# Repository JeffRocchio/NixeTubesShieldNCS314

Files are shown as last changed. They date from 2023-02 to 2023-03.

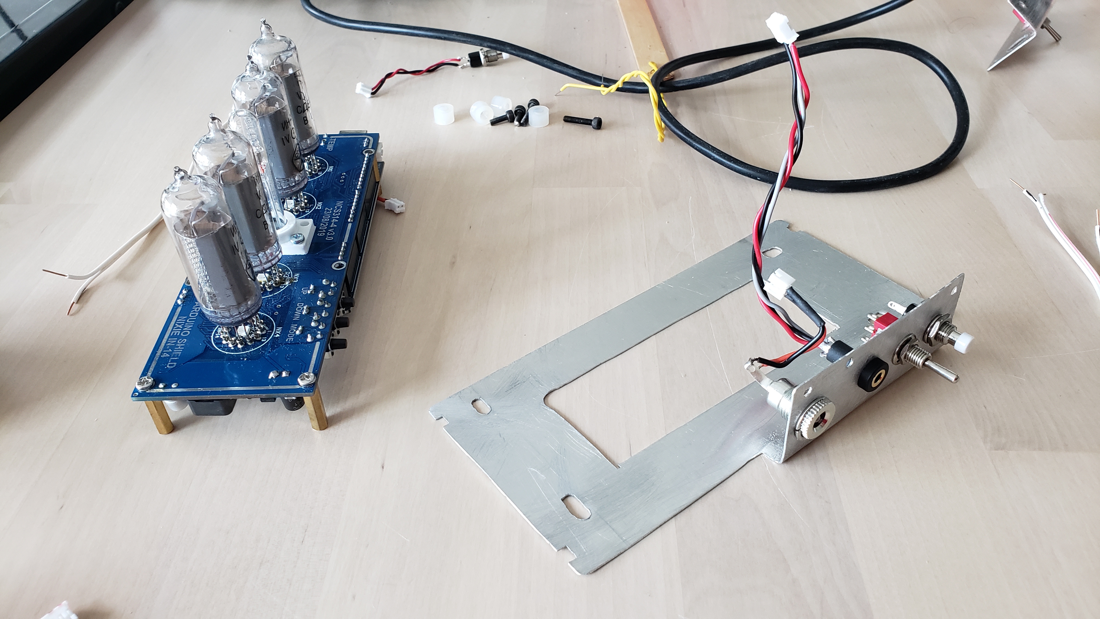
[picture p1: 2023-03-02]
Case/Fabrication_Bottom-Plate_02.jpg

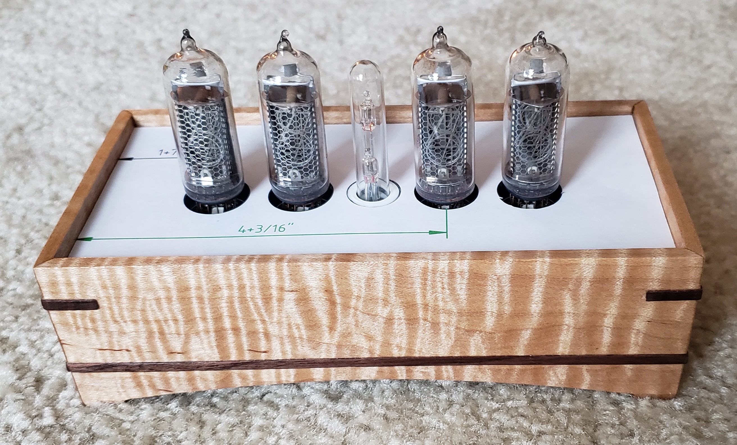
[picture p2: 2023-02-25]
Case/Fabrication_Ready4TopPlate.jpg

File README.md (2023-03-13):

This repo contains my personal customizations for the Nixi-Tube clock I purchased, and assembled, from GRA & AFCH in early 2023.

The clock is their Arduino Shield Nixie IN-14 model. I purchased the kit and assembled it; and with the help of a woodworking friend made a case for it.

<b>NOTE</b>: As of 3/13/2023 this clock does not support automatic Daylight Savings / Standard Time sensing and adjustment. To adjust for daylight savings if using the GPS receiver to sync time, you need to set the "timezone" ahead by one hour. levinedl's github has code for auto daylight savings adjustment, which was submitted as a pull request to gra-afch, tho they have ignored it. Sometime prior to the next shift back to Standard Time in the US I plan to review and incorporate levinedl's DST branch into my own code. See @ https://github.com/levinedl/NixeTubesShieldNCS314/tree/dst/Firmware/Source%20code/Hardware%20Version%203.x%20(HW3.2)/NixieClockShield_NCS314.

Per original GRA & AFCH Readme:

Sketch for Arduino UNO and Nixie Tubes Shield NCS314 and NCS312 by GRA &amp; AFCH

1. This repository content sources of project for Nixie Clock developed by GRA & AFCH.

	Folders description:
  
	FIRMWARES - source code that must be complied in Arduino IDE, and allready compiled Binary files in *.hex format ready to be uploaded on to property board by flasher.
  
	GRA & AFCH Compiled Firmware Flasher - flasher (uploader) that must be used in prevois step.
  
	LIBRARIES - Arduino libraries without which compiling will be failed. That folders must be copied to Arduino LIBRARIES folder, (default path: C:\Users\USER_NAME\Documents\Arduino\libraries)
  
	SCHEMES - electrical shemes for boards: for Nixie Clock Main Units - MCU, and for Nixie Tubes Boards
  
	USB DRIVERS - drivers for USB-to-SERIAL(UART) converters
  
	USER MANUAL - end user's manuals.

2. Link to YouTube video with preparing, compiling and uploading firmware to clock:
https://youtu.be/DQZWPn0iAHw

3. Compatibility:

	Nixie Clock Shield for Arduino - <b>NCS314</b> (Hardware Versions: HW1.0, HW1.1, HW1.2, HW2.0, HW2.2) <br>
	Nixie Clock Shield for Arduino - <b>NCS312</b> (Hardware Versions: HW1.0 - HW1.3) - use the firmware for NCS314 version 2.0
	
The GRA & AFCH on-line presence is at: http://gra-afch.com

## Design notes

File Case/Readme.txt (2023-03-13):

Custom Wooden Case for Nixi Clock

With the help of a woodworking friend I make my own case for the clock. This folder contains some photos and FreeCAD files I used to help with the design and fabrication.

NOTE: File: Nixie_Clock_SHIELD_NCS314_v3.4-4Tubes.rar is a compressed, archive, file that contains a CAD 'step' file from the GRA & AFCH web site which contains a 3D rendering of the completed circut board (but without the Arduino). I didn't discover this existed until after I had made my case. Assuming this CAD file is accurate it could be a big help in using a CAD tool, such as FreeCAD, to design, dimension, and fabricate a case.

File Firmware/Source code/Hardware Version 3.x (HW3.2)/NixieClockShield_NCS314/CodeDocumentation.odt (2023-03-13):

Nixi Tube Clock

# Arduino Code Documentation

Release tbd

This document contains detailed Arduino code documentation for the GRA & AFCH Nixi Tube clock, model Arduino Shield Nixie IN-14 Musescore plugin. Within the code are reference numbers in the form of CD-##. Those are pointers to the matching reference ID number within this document.

## Outstanding TO-DOs

Ref# | TO-DO Description
| EU/US Date Flip. The thing where the euro date format shows first for a flash, then it flips to the US date format.
| Create Night Sleep Timer: Create code to put the display tubes to sleep at night, and auto-wake up in the morning.

Add Support for Daylight Savings Time: On March 12, 2023 I noted that the clock does not automatically recognize DST. When I set the time ahead 1-hour manually (using the buttons on the back of the clock) it kept reverting back to Standard Time. After looking at the code I realized that it was doing this because when it updated the time from the GPS satellites it was simply using the hoursOffset variable to set the local time. And of course the GPS system is giving the clock UTC, with no time zone or daylight savings info. So the work-around is to set the “timezone” ahead by one hour. (And really “timezone” isn’t really a timezone, it is simply the number of hours to add/subtract from UTC in order to get the local time.) So I’d like to add support for automatic daylight savings / standard time adjustment to the software.

2023-03-13: In poking around the GRA github site I saw an ignored pull request where a Mr. Levine had created the code for this already. So this is where I should start. That is, study his code and adopt as-is or modify for my own use as appropriate. See @ https://github.com/levinedl/NixeTubesShieldNCS314/blob/dst/Firmware/Source%20code/Hardware%20Version%203.x%20(HW3.2)/NixieClockShield_NCS314/dst.ino

## Code Documentation

Ref# | Documentation

CD-01

Turn Off Arduino Internal Green LED & Remove IR Remote Feature. This is harder than it looks. Turns out that the Arduino SPI SCK and MOSI signals at pins D51 & D52 have been tied to pins D11 and D13. You can see this is the schmatic. So if you mess with pin-13, which is the hard-coded pin that the Arduino internal LED is connected to, you interfere with the clock signal for the IC which drives the nixi tube display segments (the HV57708 chip). I asked GRA/AFCH about this:

“We do not use pin 13 in our Clocks in our current configuration. And the connection is made for compatibility reasons between the UNO and MEGA, including the older versions.”

So based on this I bent over the header pin that connects into the Arduio at pin-13, such that it no longer connects into the Arduino, so that I could control PIN-13 from the Arduino code and turn that LED off in the setup code.

BUT – it also turns out that deep in the code for the infrared remote control feature is a function that blinks the internal LED on pin-13. This is inside Irremote.h. Line 81 is: # define BLINKLED 13.

Since I will never use an IR remote with this clock I have removed all the code associated with the IR remote control.

Last Update: 2023-02-12
CD-02 | RGB LEDs on One Fixed Color. This is a user-configurable feature through the mode setting functions. In the code the variable “LEDsLock” holds this setting. If LEDsLock is TRUE then the backlight LEDs are fixed on one color. The setting of LEDsLock is persistently stored in the EEPROM. If LEDsLock is TRUE, then the RDG LED colors are set from the R, G, B values that are stored in EEPROM. So you’ll see, for example: if (LEDsLock == 1) setLEDsFromEEPROM(); And void setLEDsFromEEPROM() is defined in the module rotateFireWorks_SK.ino.

CD-03

Intensity of RGB LED Under the Blinking Dots Column. Because, for me, the LED that is under the blinking dots column shines too bright, and interferes with the appearence of the blinking dots I created ability to lower the intensity of the RGB-LED under the dots column.

NOTE-1: Since I have the 4-digit clock (HH:MM) I did not attempt to make the code work for clocks with two dot columns.

NOTE-2: I hard-coded an intensity adjustment into my patch. There is no provision for a user-configurable setting via the back panel controls. To adjust the intensity you have to change the code in the the rotateFireWorks_SK.ino module.

Note-3: As I find the rotating color changes of the LEDs default behavior to be too distracting, I have set my clock to display only a single LED backlight color. Thus I have attempted to add this change to the color rotation code. However, doing so is probably just a matter of copying the code change I made in setLEDsFromEEPROM() over to the rotateFireWorks() function.

Taking note of CD-02 above, this change is implemented via updates to code that is in the rotateFireWorks_SK.ino file.

Approach: In the loop where the LED colors are set and displayed, inside of setLEDsFromEEPROM(), I reduce each R,G,B color value for the column’s pixel by the #define COLdim statement at the top of the rotateFireWorks_SK.ino file. Reducing the value of each color has the effect of retaining the set color, but dimming the brightness.

Last Update: 2023-03-02
CD-04
CD-05
CD-06

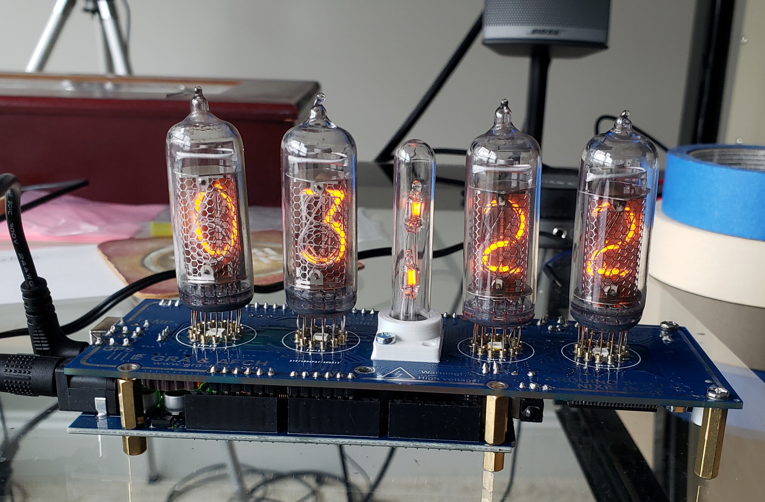
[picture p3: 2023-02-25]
Case/20230116_Bare-Chassis.jpg

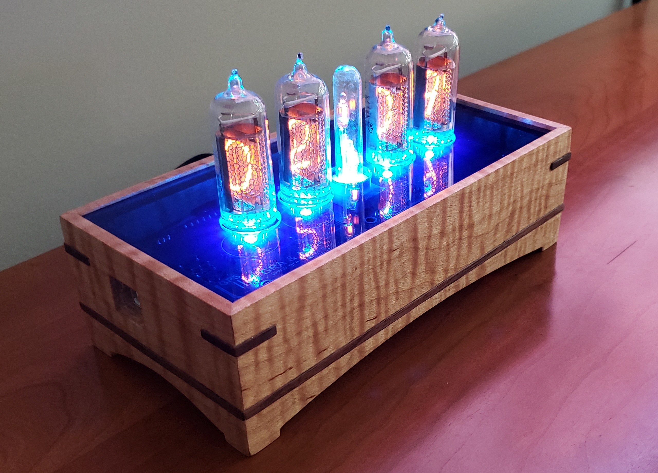
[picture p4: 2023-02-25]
Case/Finished-Case-in-Use_03.jpg

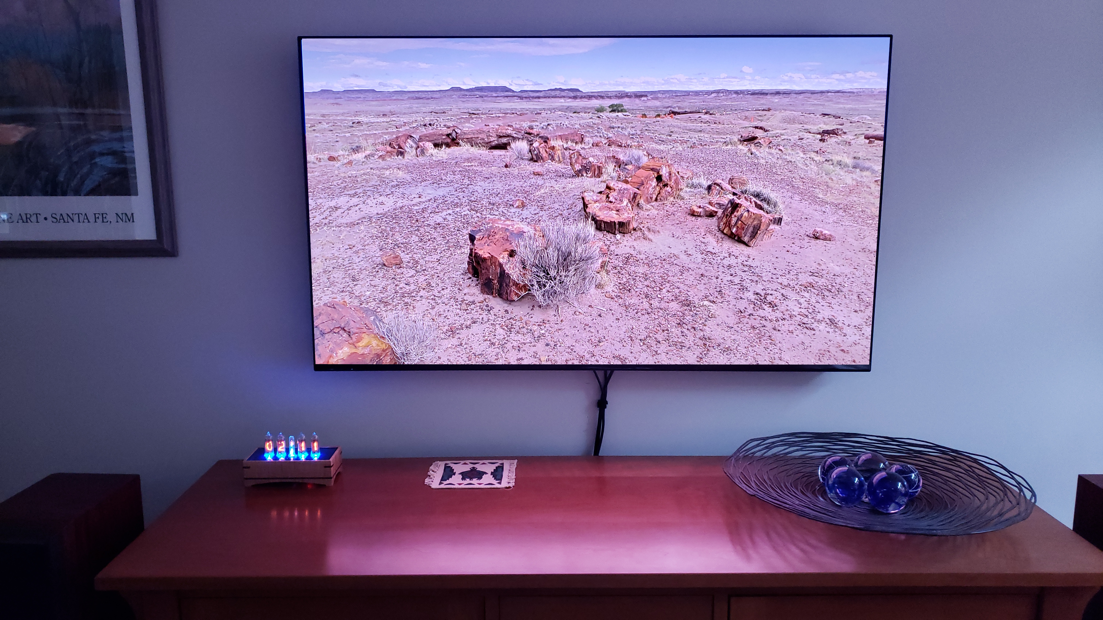
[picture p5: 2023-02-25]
Case/Finished-Case-in-Use_09.jpg

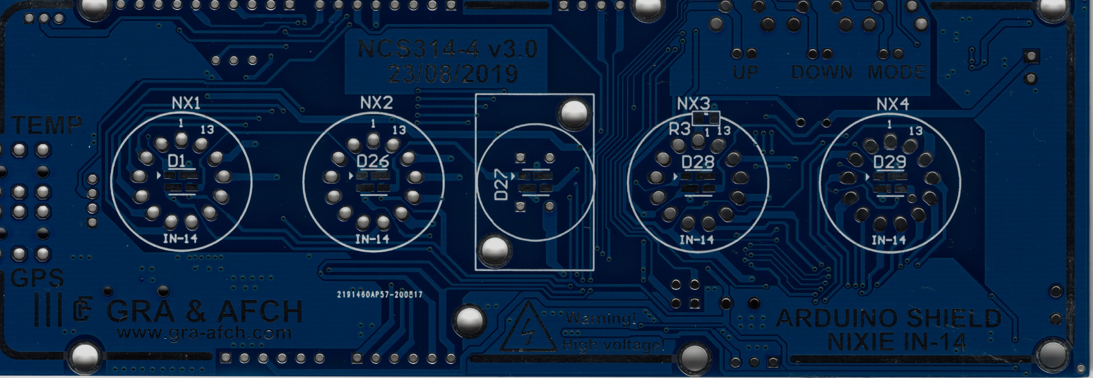
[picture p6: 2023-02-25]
Case/NixiTubeClock_CircutBoard_Scan.jpg

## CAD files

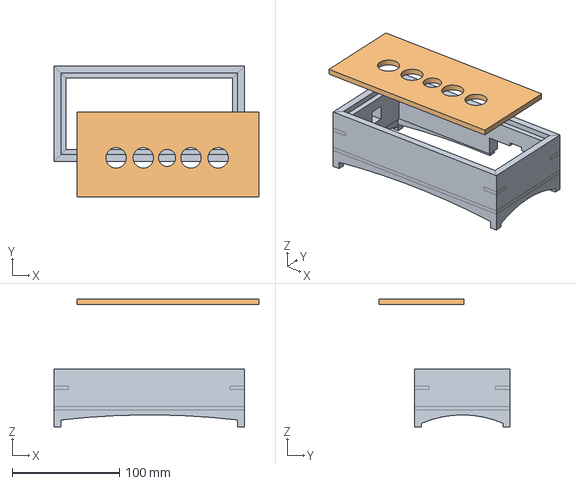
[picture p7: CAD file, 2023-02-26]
Case/FreeCAD_JeffsCase.FCStd
191.3 x 122.2 x 119.1 mm
Top Plate

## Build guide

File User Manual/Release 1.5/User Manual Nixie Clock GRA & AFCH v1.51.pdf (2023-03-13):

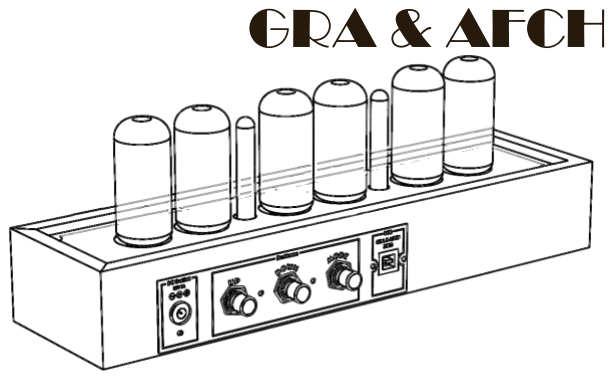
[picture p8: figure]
GRA & AFCH

# Divergence Meter

# NIXIE CLOCK

# OPERATING INSTRUCTION

2036
Release 1.51

GENERAL GUIDE

1. Press “Mode” to change fro m mo de to mode. Each mo de is ex plained in det ail o n t he fo llo wing pages.

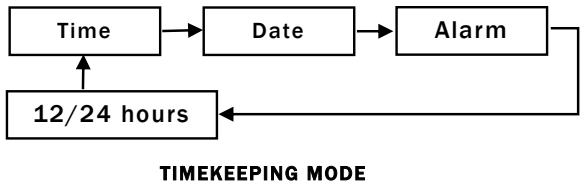
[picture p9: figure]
TIMEKEEPING MODE; Time; Date; Alarm; 12/24 hours

To set t he digit al time

1. Hold do wn “Mo de” while in t he Timekeeping Mo de unt il t he ho urs digit s start to flash. The hours flash because t hey are s elect ed.
2. Press “Mo de” to change t he selectio n in t he fo llo wing sequence:
- Once yo u reach t he Timekeeping display, yo u have to ho ld do wn “Mo de” again to display flashing ho urs.
- While the digits are select ed (flashing), hold do wn “Mode” to ret urn in Timekeeping Mo de wit hout saving.
3. While any digit s are selected, press “U p” to increase t he number, or “Do wn” to decrease t he number. Ho lding do wn “U p” or “Do wn” changes t he current selectio n at high speed.
4. Aft er you set the time, press “Mode” to select t he Timekeeping Mo de.
- If yo u do not operat e any butt on for a few minut es while select io n is flashing, the flashing sto ps and t he clo ck go es back to the Timekeeping Mo de auto mat ically .

DATE MODE

To set t he dat e

1. Hold do wn “Mo de” while in t he Dat e Mo de until the days digit s st art to flash. The day s digit s flash because t hey are selected.
Hours | Minutes | Seconds

## Timekeeping

2. Press “Mo de” to change select io n in follo wing sequence:
- Once yo u reach t he Dat e Mode , you have t o hold do wn “Mo de” again to display t he flashing day s.
- While the digits are select ed (flashing), hold do wn “Mode” to ret urn in Timekeeping Mo de wit hout saving.
3. While any digit s are selected, press “U p” to increase t he number, or “Do wn” to decrease t he number. Ho lding do wn “U p” or “Do wn” changes t he current selectio n at high speed.
4. Aft er you set t he dat e, press “Mo de” to select t he Date Mo de.
- If yo u do not operat e ant butt on fo r a few minut es while a select io n is flashing, the flashing sto ps and clock goes back to the Dat e Mode auto mat ically .
- The clo ck do es make validat io n for co rrect dat e. So clo ck not t o ret urn to Dat e Mo de if dat e is incorrect.

ALARM MODE

When the Daily Alarm Functio n is swit ched on, t he alarm sounds at t he preset t ime each day. Press any butto n to st op t he alarm after it st art s to so und.

To set t he alarm time

1. Hold do wn “Mo de” while in Alarm Mo de until t he ho ur digits st art to flash. The hour digit s flash because they are s elect ed.
2. Press “Mo de” to change select io n in t he fo llo wing s equ ence.
- Press “U p” o r “Do wn” butto ns t o increase o r decrease select ed digit s. Holding down butto ns changes the select io ns at high speed.
Days | Months | Years

## Date Mode

# web-site: www.gra-afch.com

- Daily alarm o n/o ff mo de is represent ing by upper separat e dot s, press “Up” o r “Do wn” to enable o r disable daily alarm.
- Ent ering in Alarm Mo de alway s swit ch daily alarm on.
- If y ou do not o perat e any butto ns a few minut es while a selectio n is flashing, t he flashing sto ps and t he clock go es to t he Timekeeping Mo de.

12/24 Hours Mode
To change 12/24 mo de
1. Ent er in 12/24 mode sett ings, by ho lding do wn “Mode” butt o n while in 12/24 mode until 12 o r 24 digit s st art to flash.
2. Press “U p” or “Do wn” butto ns to swit ch bet ween 12 and 24 mo des.
3. Aft er yo u set t ime format press “Mode” butto n to return i n Timekeeping mo de.
- If y ou do not o perat e any butto ns a few minut es while a selectio n is flashing, t he flashing sto ps and t he clock go es to t he Timekeeping Mo de
LED Backlight
To disable LED backlight
1. Hold down “Do wn” unt il t he LED backlight turns o ff.

To enable LED backlight
1. Hold down “U p” until the LED backlight t urns o n.

To fix co lo r of LEDs
1. Press “Do wn” butto n.

To resume auto mat ic LEDs co lo r changing
1. Pres “U p” butt on.

POWER ON SELF TEST
Immediat ely aft er a clo ck is po wered o n Self- Test is st arting in the follo wing sequence:
1. Red LEDs o n.
2. Green LEDs o n.
3. Blue LEDs on.
4. Tubes test which display all digit s fro m 0 to 9 on all t ubes simultaneo usly.
5. Input vo lt age t est.
6. Firmware versio n.
7. Sound t est .

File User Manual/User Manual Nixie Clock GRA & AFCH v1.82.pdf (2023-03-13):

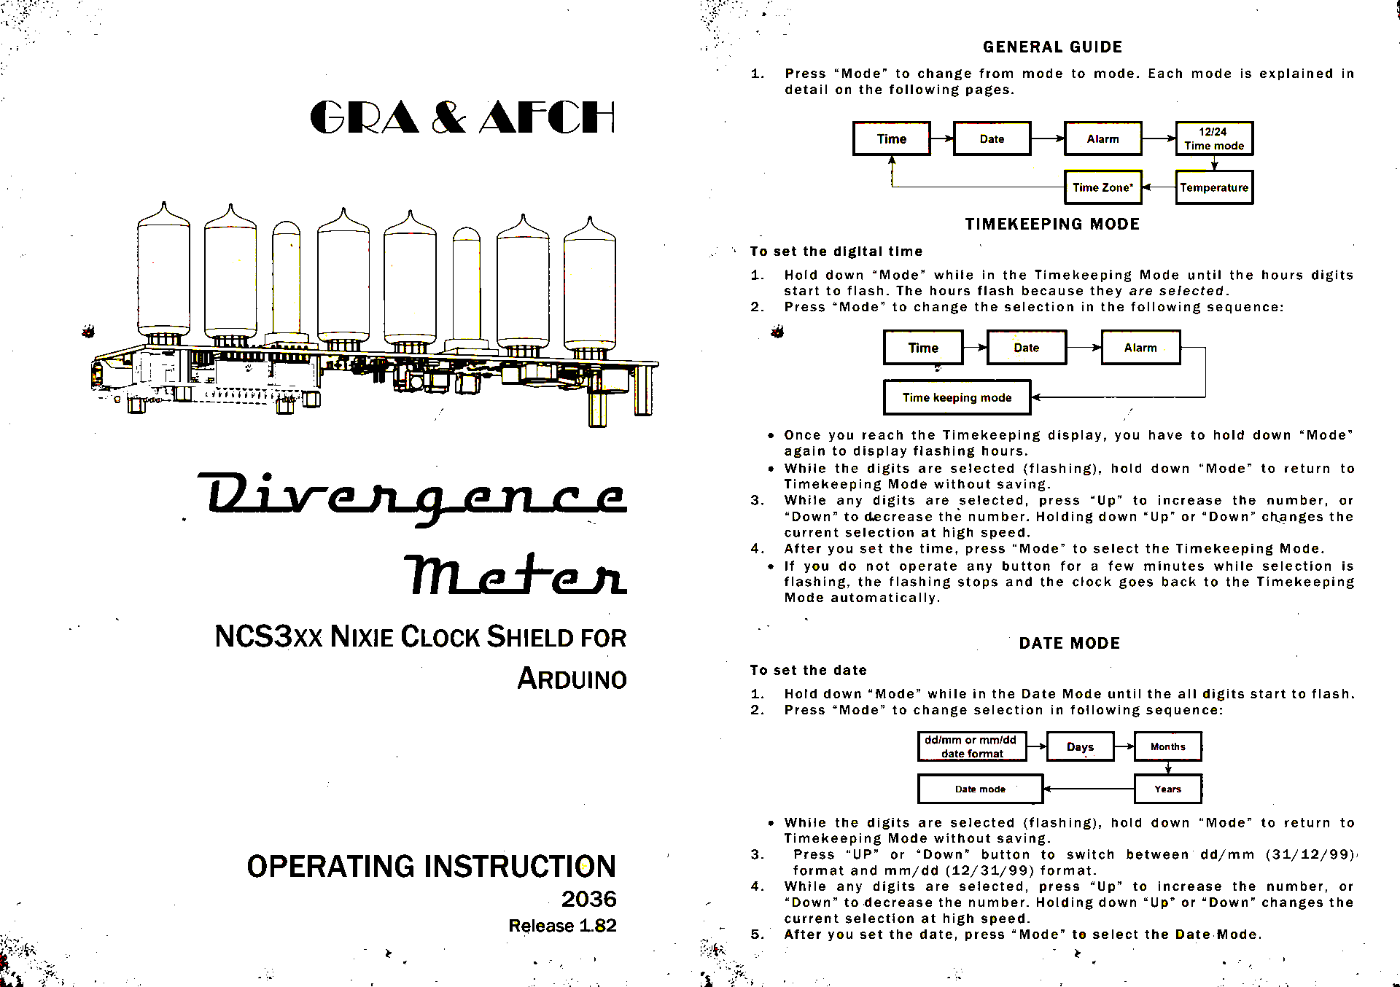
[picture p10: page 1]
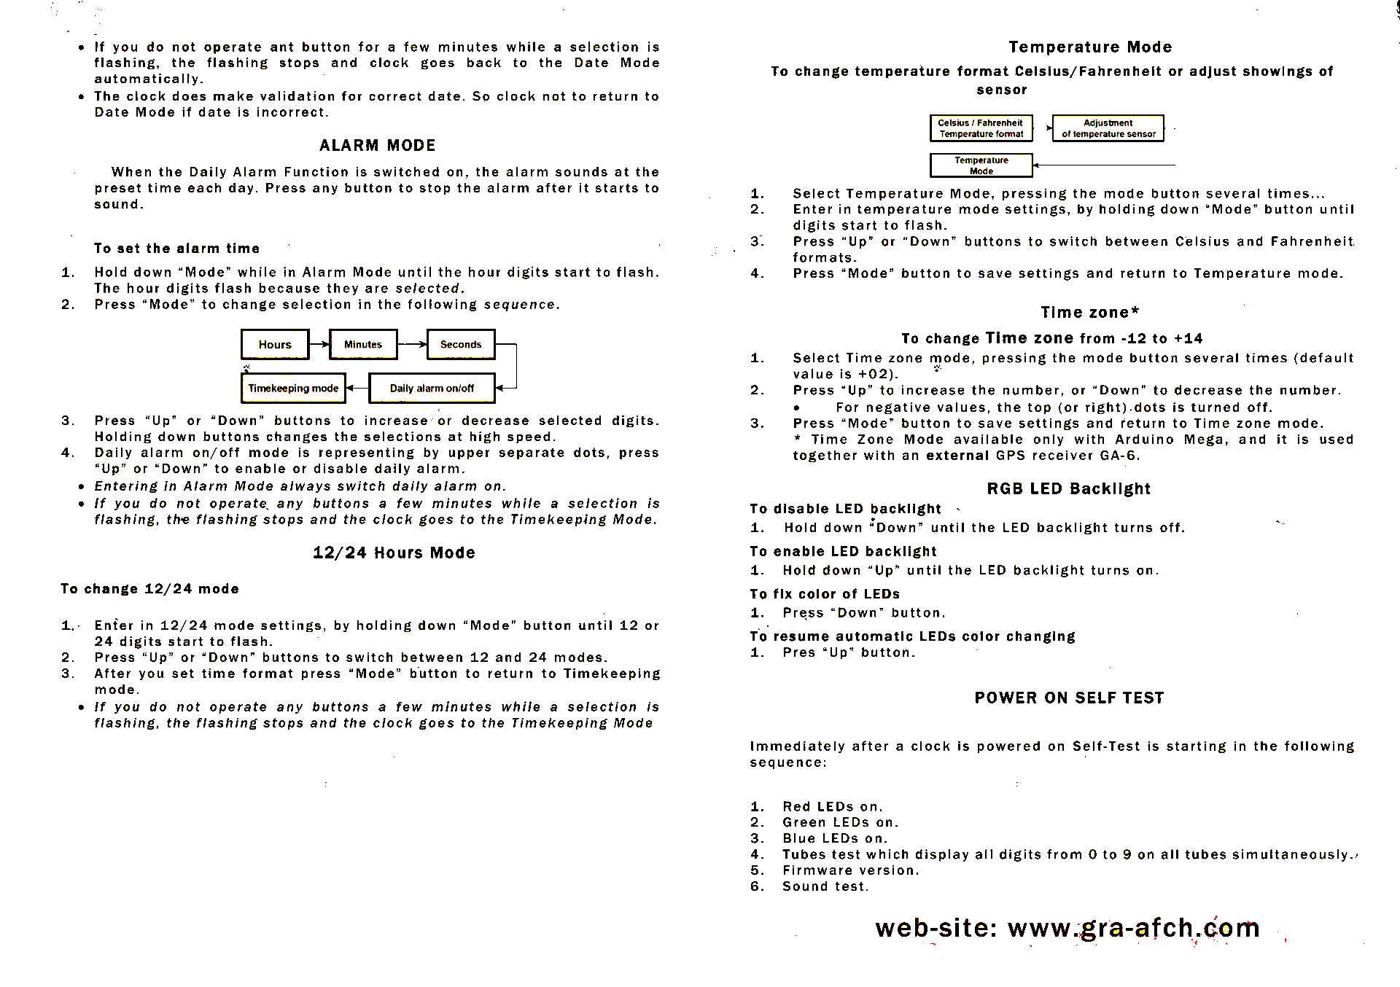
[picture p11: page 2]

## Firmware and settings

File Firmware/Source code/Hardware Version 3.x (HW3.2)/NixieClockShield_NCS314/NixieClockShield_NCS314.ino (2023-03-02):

/******************************************************************************/
//  Jeff Rocchio's Customizations.

/*  2023-03-02_a
        - Created ability for intensity of the RGB-LED under the dots column
      to be less than the intensity of the LEDs under the tubes.
      Did this because for me that LED shines too bright and interferes with
      the appearence of the blinking dots.
      NOTE-1: Since I have the 4-digit clock (HH:MM) I did not attempt to make
      the code work for clocks with two dot columns.
      NOTE-2: I hard-coded an intensity adjustment into my patch. There is
      no provision for a user-configurable setting via the back panel
      controls. To adjust the intensity you have to change the code
      in the the rotateFireWorks_SK.ino module. See the statement: #define COLdim
      See documentation note CD-03 in CodeDocumentation.odt. */

/*  2023-02-12_a
        - Removed all code associated with the IR remote control. Not only
      because I will never use this, but also because it makes use of the
      Arduino's internal LED, which prevents me from turning it off.
      See documentation note CD-01 in CodeDocumentation.odt. */

/*  2023-02-12_b
        - Turn Arduino internal LED off (as it is so bright it shines up through
      the board). NOTE: to make this work I had to bend the header pin that
      connects to Arduino pin 13 over so that the clock signal connected to
      that header pin doesn't come into the Arduino. See Documentation
      note CD-01 in CodeDocumentation.odt. */



// TO-DOs: --------------------------------------------------------------------

/* GPS Validation always 'failing
    In GPS_Parse_DateTime() it keeps falling
    into the 'Validation failed' serial.print. Yet the prior prints do show
    it is getting the time value from the GPS. So what's that about? */

/* Date:
    The thing where the euro date format shows first for a flash, then
    it flips to the US date format. */

/* Create Night Sleep Timer:
    Create code to put the display tubes to sleep at night, and auto-wake up
    in the morning. */

/*******************************************************************************/



const String FirmwareVersion = "020100"; // jrr 2023-02-12: Changing ver# for my updates. For now, Month & sequence #.
//const String FirmwareVersion = "019500";
//#define HardwareVersion "NCS314 for HW 3.x" 
const char HardwareVersion[] PROGMEM = {"NCS314 for HW 3.x"};
//Format                _X.XXX_
//NIXIE CLOCK SHIELD NCS314 v 3.x by GRA & AFCH (fominalec@gmail.com)
//1.95 14.01.2021
//GPS ANTI ROLLOVER FIX
//1.94 17.02.2021
//Added: Сhecking the presence of a gps receiver when turned on.
//Return to the previous gps parser
//1.92 21.01.2021
//Added: defines for GPS receiver types
//1.90 08.06.2020 
//Fixed: GPS timezone issue: added breakTime(now(), tm) to adjustTime function at Time.cpp
//1.89 03.04.2020
//Dots sync with seconds
//1.88 26.03.2020
//GPS synchronization algorithm has been changed
//1.87 11.03.2020
//SPI MODE was changed from MODE1 to MODE3
//1.86 23.02.2020
//GPS synchronization algorithm changed
//GPS parser has been replaced by NEOGPS
//1.85.2 23.02.2020
//Added: DS3231 internal temperature sensor self test: 5 beeps if fail.
//1.85 21.02.2020
//Fixed: Bug with time zones more than +-9
//1.84 08.04.2018
//LEDs functions moved to external file
//LEDs freezing while music (or sound) played.
//SPI Setup moved driver's file
//1.83 02.08.2018 (Driver v 1.1 is required)
//Fixed: Temp. reading speed fixed
//Fixed: Dots mixed up (driver was updated to v. 1.1)
//Fixed: RGB LEDs reading from EEPROM
//Fixed: Check for entering data from GPS in range
//1.82  18.07.2018 Dual Date Format
//1.81  18.02.2018 Temp. sensor present analyze
//1.80   06.08.2017
//Added: Date and Time GPS synchronization
//1.70   30.07.2017
//Added  IR remote control support (Sony RM-X151) ("MODE", "UP", "DOWN")
//1.60   24_07_2017
//Added: Temperature reading mode in menu and slot machine transaction
//1.0.31 27_04_2017
//Added: antipoisoning effect - slot machine
//1.021 31.01.2017
//Added: time synchronizing each 10 seconds
//Fixed: not correct time reading from RTC while start up
//1.02 17.10.2016
//Fixed: RGB color controls
//Update to Arduino IDE 1.6.12 (Time.h replaced to TimeLib.h)
//1.01
//Added RGB LEDs lock(by UP and Down Buttons)
//Added Down and Up buttons pause and resume self testing
//25.09.2016 update to HW ver 1.1
//25.05.2016

//#define tubes8
#define tubes6 // NOTE: Per GFA/AFCH this is correct, even for 4-tube clocks.

#include <SPI.h>
#include <Wire.h>
#include <ClickButton.h>
#include <TimeLib.h>
#ifndef GRA_AND_AFCH_TIME_LIB_MOD
  #error The "Time (TimeLib)" library modified by GRA and AFCH must be used!
#endif
#include <Tone.h>
#include <EEPROM.h>
#include "doIndication314_HW3.x.h"
#include <OneWire.h>


#define ARDUINO_LED 13 // 2023-02-12_b: Pin internal LED is wired to


/* I believe this #IF block is here because you can only
    use a GPS receiver if you have the ATmega#### arduino. */

#if defined(__AVR_ATmega1280__) || defined(__AVR_ATmega2560__)

#define GPS_SYNC_INTERVAL 1800000 // in milliseconds
//#define GPS_SYNC_INTERVAL 180000 //3 minutes
unsigned long Last_Time_GPS_Sync = 0;
//bool GPS_Sync_Flag = false;
//uint32_t GPS_Sync_Interval=120000; // 2 minutes
uint32_t GPS_Sync_Interval = 60000; // first try = 1 minute
uint32_t MillsNow=0;
#define TIME_TO_TRY 60000 //1 minute
bool AttMsgWasShowed=false;

#define GPS_BUFFER_LENGTH 83

char GPS_Package[GPS_BUFFER_LENGTH];
byte GPS_position = 0;

struct GPS_DATE_TIME
{
  byte GPS_hours;
  byte GPS_minutes;
  byte GPS_seconds;
  byte GPS_day;
  byte GPS_mounth;
  int GPS_year;
  bool GPS_Valid_Data = false;
  unsigned long GPS_Data_Parsed_time;
};

GPS_DATE_TIME GPS_Date_Time;

#endif // CLOSES: #if defined(__AVR_ATmega1280__) || defined(__AVR_ATmega2560__)

boolean UD, LD; // DOTS control;

byte data[12];
byte addr[8];
int celsius, fahrenheit;

#define pinSet A0
#define pinUp A2
#define pinDown A1
const byte pinBuzzer = 2; // pomenyal
#define pinUpperDots 12 //HIGH value light a dots
#define pinLowerDots 8 //HIGH value light a dots
#define pinTemp 7
#define pinSHDN 5
bool RTC_present;
#define US_DateFormat 1
#define EU_DateFormat 0
//bool DateFormat=EU_DateFormat;

OneWire ds(pinTemp);
bool TempPresent = false;
#define CELSIUS 0
#define FAHRENHEIT 1

String stringToDisplay = "000000"; // Conten of this string will be displayed on tubes (must be 6 chars length)
int menuPosition = 0; 
// 0 - time
// 1 - date
// 2 - alarm
// 3 - 12/24 hours mode
// 4 - Temperature

byte blinkMask = B00000000; //bit mask for blinkin digits (1 - blink, 0 - constant light)
int blankMask = B00000000; //bit mask for digits (1 - off, 0 - on)

byte dotPattern = B00000000; //bit mask for separeting dots (1 - on, 0 - off)
//B10000000 - upper dots
//B01000000 - lower dots

#define DS1307_ADDRESS 0x68
byte zero = 0x00; //workaround for issue #527
int RTC_hours, RTC_minutes, RTC_seconds, RTC_day, RTC_month, RTC_year, RTC_day_of_week;

#define TimeIndex        0
#define DateIndex        1
#define AlarmIndex       2
#define hModeIndex       3
#define TemperatureIndex 4
#define TimeZoneIndex    5
#define TimeHoursIndex   6
#define TimeMintuesIndex 7
#define TimeSecondsIndex 8
#define DateFormatIndex  9 
#define DateDayIndex     10
#define DateMonthIndex   11
#define DateYearIndex    12
#define AlarmHourIndex   13
#define AlarmMinuteIndex 14
#define AlarmSecondIndex 15
#define Alarm01          16
#define hModeValueIndex  17
#define DegreesFormatIndex 18
#define HoursOffsetIndex 19

#define FirstParent      TimeIndex
#define LastParent       TimeZoneIndex
#define SettingsCount    (HoursOffsetIndex+1)
#define NoParent         0
#define NoChild          0

//-------------------------------0--------1--------2-------3--------4--------5--------6--------7--------8--------9----------10-------11---------12---------13-------14-------15---------16---------17--------18----------19
//                     names:  Time,   Date,   Alarm,   12/24, Temperature,TimeZone,hours,   mintues, seconds, DateFormat, day,    month,   year,      hour,   minute,   second alarm01  hour_format Deg.FormIndex HoursOffset
//                               1        1        1       1        1        1        1        1        1        1          1        1          1          1        1        1        1            1         1        1
int parent[SettingsCount] = {NoParent, NoParent, NoParent, NoParent,NoParent,NoParent,1,       1,       1,       2,         2,       2,         2,         3,       3,       3,       3,       4,           5,        6};
int firstChild[SettingsCount] = {6,       9,       13,     17,      18,      19,      0,       0,       0,    NoChild,      0,       0,         0,         0,       0,       0,       0,       0,           0,        0};
int lastChild[SettingsCount] = { 8,      12,       16,     17,      18,      19,      0,       0,       0,    NoChild,      0,       0,         0,         0,       0,       0,       0,       0,           0,        0};
int value[SettingsCount] = {     0,       0,       0,      0,       0,       0,       0,       0,       0,  EU_DateFormat,  0,       0,         0,         0,       0,       0,       0,       24,          0,        2};
int maxValue[SettingsCount] = {  0,       0,       0,      0,       0,       0,       23,      59,      59, US_DateFormat,  31,      12,        99,       23,      59,      59,       1,       24,     FAHRENHEIT,    14};
int minValue[SettingsCount] = {  0,       0,       0,      12,      0,       0,       00,      00,      00, EU_DateFormat,  1,       1,         00,       00,      00,      00,       0,       12,      CELSIUS,     -12};
int blinkPattern[SettingsCount] = {  
  B00000000, //0
  B00000000, //1
  B00000000, //2
  B00000000, //3
  B00000000, //4
  B00000000, //5
  B00000011, //6
  B00001100, //7
  B00110000, //8
  B00111111, //9
  B00000011, //10
  B00001100, //11
  B00110000, //12
  B00000011, //13
  B00001100, //14
  B00110000, //15
  B11000000, //16
  B00001100, //17
  B00111111, //18
  B00000011, //19
};

bool editMode = false;

long downTime = 0;
long upTime = 0;
const long settingDelay = 150;
bool BlinkUp = false;
bool BlinkDown = false;
unsigned long enteringEditModeTime = 0;
bool RGBLedsOn = true;
#define RGBLEDsEEPROMAddress 0
#define HourFormatEEPROMAddress 1
#define AlarmTimeEEPROMAddress 2 //3,4,5
#define AlarmArmedEEPROMAddress 6
#define LEDsLockEEPROMAddress 7
#define LEDsRedValueEEPROMAddress 8
#define LEDsGreenValueEEPROMAddress 9
#define LEDsBlueValueEEPROMAddress 10
#define DegreesFormatEEPROMAddress 11
#define HoursOffsetEEPROMAddress 12
#define DateFormatEEPROMAddress 13

//buttons pins declarations
ClickButton setButton(pinSet, LOW, CLICKBTN_PULLUP);
ClickButton upButton(pinUp, LOW, CLICKBTN_PULLUP);
ClickButton downButton(pinDown, LOW, CLICKBTN_PULLUP);
///////////////////

Tone tone1;
#define isdigit(n) (n >= '0' && n <= '9')
//char *song = "MissionImp:d=16,o=6,b=95:32d,32d#,32d,32d#,32d,32d#,32d,32d#,32d,32d,32d#,32e,32f,32f#,32g,g,8p,g,8p,a#,p,c7,p,g,8p,g,8p,f,p,f#,p,g,8p,g,8p,a#,p,c7,p,g,8p,g,8p,f,p,f#,p,a#,g,2d,32p,a#,g,2c#,32p,a#,g,2c,a#5,8c,2p,32p,a#5,g5,2f#,32p,a#5,g5,2f,32p,a#5,g5,2e,d#,8d";
char *song = "PinkPanther:d=4,o=5,b=160:8d#,8e,2p,8f#,8g,2p,8d#,8e,16p,8f#,8g,16p,8c6,8b,16p,8d#,8e,16p,8b,2a#,2p,16a,16g,16e,16d,2e";
//char *song="VanessaMae:d=4,o=6,b=70:32c7,32b,16c7,32g,32p,32g,32p,32d#,32p,32d#,32p,32c,32p,32c,32p,32c7,32b,16c7,32g#,32p,32g#,32p,32f,32p,16f,32c,32p,32c,32p,32c7,32b,16c7,32g,32p,32g,32p,32d#,32p,32d#,32p,32c,32p,32c,32p,32g,32f,32d#,32d,32c,32d,32d#,32c,32d#,32f,16g,8p,16d7,32c7,32d7,32a#,32d7,32a,32d7,32g,32d7,32d7,32p,32d7,32p,32d7,32p,16d7,32c7,32d7,32a#,32d7,32a,32d7,32g,32d7,32d7,32p,32d7,32p,32d7,32p,32g,32f,32d#,32d,32c,32d,32d#,32c,32d#,32f,16c";
//char *song="DasBoot:d=4,o=5,b=100:d#.4,8d4,8c4,8d4,8d#4,8g4,a#.4,8a4,8g4,8a4,8a#4,8d,2f.,p,f.4,8e4,8d4,8e4,8f4,8a4,c.,8b4,8a4,8b4,8c,8e,2g.,2p";
//char *song="Scatman:d=4,o=5,b=200:8b,16b,32p,8b,16b,32p,8b,2d6,16p,16c#.6,16p.,8d6,16p,16c#6,8b,16p,8f#,2p.,16c#6,8p,16d.6,16p.,16c#6,16b,8p,8f#,2p,32p,2d6,16p,16c#6,8p,16d.6,16p.,16c#6,16a.,16p.,8e,2p.,16c#6,8p,16d.6,16p.,16c#6,16b,8p,8b,16b,32p,8b,16b,32p,8b,2d6,16p,16c#.6,16p.,8d6,16p,16c#6,8b,16p,8f#,2p.,16c#6,8p,16d.6,16p.,16c#6,16b,8p,8f#,2p,32p,2d6,16p,16c#6,8p,16d.6,16p.,16c#6,16a.,16p.,8e,2p.,16c#6,8p,16d.6,16p.,16c#6,16a,8p,8e,2p,32p,16f#.6,16p.,16b.,16p.";
//char *song="Popcorn:d=4,o=5,b=160:8c6,8a#,8c6,8g,8d#,8g,c,8c6,8a#,8c6,8g,8d#,8g,c,8c6,8d6,8d#6,16c6,8d#6,16c6,8d#6,8d6,16a#,8d6,16a#,8d6,8c6,8a#,8g,8a#,c6";
//char *song="WeWishYou:d=4,o=5,b=200:d,g,8g,8a,8g,8f#,e,e,e,a,8a,8b,8a,8g,f#,d,d,b,8b,8c6,8b,8a,g,e,d,e,a,f#,2g,d,g,8g,8a,8g,8f#,e,e,e,a,8a,8b,8a,8g,f#,d,d,b,8b,8c6,8b,8a,g,e,d,e,a,f#,1g,d,g,g,g,2f#,f#,g,f#,e,2d,a,b,8a,8a,8g,8g,d6,d,d,e,a,f#,2g";
#define OCTAVE_OFFSET 0
char *p;

int notes[] = { 0,
                NOTE_C4, NOTE_CS4, NOTE_D4, NOTE_DS4, NOTE_E4, NOTE_F4, NOTE_FS4, NOTE_G4, NOTE_GS4, NOTE_A4, NOTE_AS4, NOTE_B4,
                NOTE_C5, NOTE_CS5, NOTE_D5, NOTE_DS5, NOTE_E5, NOTE_F5, NOTE_FS5, NOTE_G5, NOTE_GS5, NOTE_A5, NOTE_AS5, NOTE_B5,
                NOTE_C6, NOTE_CS6, NOTE_D6, NOTE_DS6, NOTE_E6, NOTE_F6, NOTE_FS6, NOTE_G6, NOTE_GS6, NOTE_A6, NOTE_AS6, NOTE_B6,
                NOTE_C7, NOTE_CS7, NOTE_D7, NOTE_DS7, NOTE_E7, NOTE_F7, NOTE_FS7, NOTE_G7, NOTE_GS7, NOTE_A7, NOTE_AS7, NOTE_B7
              };
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
void loop() {

  if (((millis() % 10000) == 0) && (RTC_present)) //synchronize with RTC every 10 seconds
  {
    getRTCTime();
    setTime(RTC_hours, RTC_minutes, RTC_seconds, RTC_day, RTC_month, RTC_year);
    //Serial.println(F("Sync"));
  }

  /*  GPS device can only be used with clock models that use the ATmega Arduinos. So in the below we
      are getting time/date info from the GPS and updating the real-time clock chip accordingly. */
  #if defined(__AVR_ATmega1280__) || defined(__AVR_ATmega2560__)
    MillsNow=millis();
    if ((MillsNow - Last_Time_GPS_Sync) > GPS_Sync_Interval) // <!-----! 13.01.2022
    {
      if (AttMsgWasShowed==false) 
      {
        Serial.println(F("Attempt to sync with GPS."));
        AttMsgWasShowed=true;
      }
      GetDataFromSerial1();
    } 
    if ((MillsNow - Last_Time_GPS_Sync) > GPS_Sync_Interval + TIME_TO_TRY) 
    {
      Last_Time_GPS_Sync=MillsNow; //if it is not possible to synchronize within the allotted time TIME_TO_TRY, then we postpone attempts to the next time interval.
      Serial.println(F("All attempts were unsuccessful."));
      AttMsgWasShowed=false;
    }
  #endif // CLOSES: GPS acquisition.

  /*   2023-02-12: This is weird to me. playmusic(p) will play the current song, unless the value of 
      p has been set to zero. Which it is set to zero here and there. But I can't work out what value
      it has as we continually loop through here. It isn't constantly playing, so it must be set to
      zer0 as the 'norm' for passes through here. I think *maybe* it is set to the default song
      the 1st time through, right after the setup() routine has run. */
  p = playmusic(p);

  /*  Change colors on the backlight LEDs under the tubes. (the call to
      rotateFireWorks() will determine if this actually occurs or not
      based on user config settings - e.g., if LEDs should be off or
      only 1-set color). */
  if ((millis() - prevTime4FireWorks) > LEDsDelay)
  {
    rotateFireWorks(); //change color (by 1 step)
    prevTime4FireWorks = millis();
  }

  if ((menuPosition == TimeIndex) || (modeChangedByUser == false) ) modesChanger();
  doIndication();

  setButton.Update();
  upButton.Update();
  downButton.Update();
  if (editMode == false)
  {
    blinkMask = B00000000;

  } else if ((millis() - enteringEditModeTime) > 60000)
  {
    editMode = false;
    menuPosition = firstChild[menuPosition];
    blinkMask = blinkPattern[menuPosition];
  }
  if (setButton.clicks > 0) //short click
  {
    modeChangedByUser = true;
    p = 0; //shut off music )))
    tone1.play(1000, 100);
    enteringEditModeTime = millis();
    /*if (value[DateFormatIndex] == US_DateFormat)
    {
      //if (menuPosition == )
    } else */
    menuPosition = menuPosition + 1;
    #if defined (__AVR_ATmega328P__)
      if (menuPosition == TimeZoneIndex) menuPosition++;// skip TimeZone for Arduino Uno
    #endif
    if (menuPosition == LastParent + 1) menuPosition = TimeIndex;
    /*Serial.print(F("menuPosition="));
    Serial.println(menuPosition);
    Serial.print(F("value="));
    Serial.println(value[menuPosition]);*/

    blinkMask = blinkPattern[menuPosition];
    if ((parent[menuPosition - 1] != 0) and (lastChild[parent[menuPosition - 1] - 1] == (menuPosition - 1))) //exit from edit mode
    {
      if ((parent[menuPosition - 1] - 1 == 1) && (!isValidDate()))
      {
        menuPosition = DateDayIndex;
        return;
      }
      editMode = false;
      menuPosition = parent[menuPosition - 1] - 1;
      if (menuPosition == TimeIndex) setTime(value[TimeHoursIndex], value[TimeMintuesIndex], value[TimeSecondsIndex], day(), month(), year());
      if (menuPosition == DateIndex) 
      {
        Serial.print(F("Day:"));
        Serial.println(value[DateDayIndex]);
        Serial.print(F("Month:"));
        Serial.println(value[DateMonthIndex]);
        setTime(hour(), minute(), second(), value[DateDayIndex], value[DateMonthIndex], 2000 + value[DateYearIndex]);
        EEPROM.write(DateFormatEEPROMAddress, value[DateFormatIndex]);
      }
      if (menuPosition == AlarmIndex) {
        EEPROM.write(AlarmTimeEEPROMAddress, value[AlarmHourIndex]);
        EEPROM.write(AlarmTimeEEPROMAddress + 1, value[AlarmMinuteIndex]);
        EEPROM.write(AlarmTimeEEPROMAddress + 2, value[AlarmSecondIndex]);
        EEPROM.write(AlarmArmedEEPROMAddress, value[Alarm01]);
      };
      if (menuPosition == hModeIndex) EEPROM.write(HourFormatEEPROMAddress, value[hModeValueIndex]);
      if (menuPosition == TemperatureIndex)
      {
        EEPROM.write(DegreesFormatEEPROMAddress, value[DegreesFormatIndex]);
      }
      if (menuPosition == TimeZoneIndex) EEPROM.write(HoursOffsetEEPROMAddress, value[HoursOffsetIndex] - minValue[HoursOffsetIndex]);
      //if (menuPosition == hModeIndex) EEPROM.write(HourFormatEEPROMAddress, value[hModeValueIndex]);
      setRTCDateTime(hour(), minute(), second(), day(), month(), year() % 1000, 1);
      return;
    } //end exit from edit mode
    /*Serial.print("menu pos=");
    Serial.println(menuPosition);
    Serial.print("DateFormat");
    Serial.println(value[DateFormatIndex]);*/
    if ((menuPosition != HoursOffsetIndex) &&
        (menuPosition != DateFormatIndex) &&
        (menuPosition != DateDayIndex)) value[menuPosition] = extractDigits(blinkMask);
  }
   if (setButton.clicks < 0) //long click
  {
    tone1.play(1000, 100);
    if (!editMode)
    {
      enteringEditModeTime = millis();
      if (menuPosition == TimeIndex) stringToDisplay = PreZero(hour()) + PreZero(minute()) + PreZero(second()); //temporary enabled 24 hour format while settings
    }
    if (menuPosition == DateIndex) 
    {
     // Serial.println("DateEdit");
      value[DateDayIndex] =  day();
      value[DateMonthIndex] = month();
      value[DateYearIndex] = year() % 1000;
      if (value[DateFormatIndex] == EU_DateFormat) stringToDisplay=PreZero(value[DateDayIndex])+PreZero(value[DateMonthIndex])+PreZero(value[DateYearIndex]);
        else stringToDisplay=PreZero(value[DateMonthIndex])+PreZero(value[DateDayIndex])+PreZero(value[DateYearIndex]);
      //Serial.print("str=");
     // Serial.println(stringToDisplay);
    }
    menuPosition = firstChild[menuPosition];
    if (menuPosition == AlarmHourIndex) {
      value[Alarm01] = 1; /*digitalWrite(pinUpperDots, HIGH);*/dotPattern = B10000000;
    }
    editMode = !editMode;
    blinkMask = blinkPattern[menuPosition];
    if ((menuPosition != DegreesFormatIndex) && 
        (menuPosition != HoursOffsetIndex) &&
        (menuPosition != DateFormatIndex))
      value[menuPosition] = extractDigits(blinkMask);
    /*Serial.print(F("menuPosition="));
    Serial.println(menuPosition);
    Serial.print(F("value="));
    Serial.println(value[menuPosition]);  */
  }

  if (upButton.clicks != 0) functionUpButton = upButton.clicks;

  if (upButton.clicks > 0)
  {
    modeChangedByUser = true;
    p = 0; //shut off music )))
    tone1.play(1000, 100);
    incrementValue();
    if (!editMode)
    {
      LEDsLock = false;
      EEPROM.write(LEDsLockEEPROMAddress, 0);
    }
  }

  if (functionUpButton == -1 && upButton.depressed == true)
  {
    BlinkUp = false;
    if (editMode == true)
    {
      if ( (millis() - upTime) > settingDelay)
      {
        upTime = millis();// + settingDelay;
        incrementValue();
      }
    }
  } else BlinkUp = true;

  if (downButton.clicks != 0) functionDownButton = downButton.clicks;

  if (downButton.clicks > 0)
  {
    modeChangedByUser = true;
    p = 0; //shut off music )))
    tone1.play(1000, 100);
    dicrementValue();
    if (!editMode)
    {
      LEDsLock = true;
      EEPROM.write(LEDsLockEEPROMAddress, 1);
      EEPROM.write(LEDsRedValueEEPROMAddress, RedLight);
      EEPROM.write(LEDsGreenValueEEPROMAddress, GreenLight);
      EEPROM.write(LEDsBlueValueEEPROMAddress, BlueLight);
      /*Serial.println(F("Store to EEPROM:"));
      Serial.print(F("RED="));
      Serial.println(RedLight);
      Serial.print(F("GREEN="));
      Serial.println(GreenLight);
      Serial.print(F("Blue="));
      Serial.println(BlueLight);*/
    }
  }

  if (functionDownButton == -1 && downButton.depressed == true)
  {
    BlinkDown = false;
    if (editMode == true)
    {
      if ( (millis() - downTime) > settingDelay)
      {
        downTime = millis();// + settingDelay;
        dicrementValue();
      }
    }
  } else BlinkDown = true;
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

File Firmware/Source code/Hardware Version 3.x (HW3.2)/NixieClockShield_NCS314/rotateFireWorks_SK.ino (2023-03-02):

/******************************************************************************/
//  Jeff Rocchio's Customizations.

/*  2023-03-02_a
        - Created ability for intensity of the RGB-LED under the dots column
      to be less than the intensity of the LEDs under the tubes.
      Did this because for me that LED shines too bright and interferes with
      the appearence of the blinking dots.
      NOTE-1: Since I have the 4-digit clock (HH:MM) I did not attempt to make
      the code work for clocks with two dot columns.
      NOTE-2: I hard-coded an intensity adjustment into my patch. There is
      no provision for a user-configurable setting via the back panel
      controls. To adjust the intensity you have to change the code
      in the the rotateFireWorks_SK.ino module.
      See documentation note CD-03 in CodeDocumentation.odt. */

/*  2023-03-02_b
        - Removed the obsolete lines of code that had been commented 
      out in the original source code I cloned. Did this to make the code
      a bit easier to follow. */

#include <Adafruit_NeoPixel.h>

#define PIN            6
#define NUMPIXELS      8
#define LEDsSpeed      10
#define COLdim         50 // 2023-03-02_a: Percent to dim the RGB LED under the blinking dots column.
const int LEDsDelay=40;

Adafruit_NeoPixel pixels = Adafruit_NeoPixel(NUMPIXELS, PIN, NEO_GRB + NEO_KHZ800);

void LEDsSetup()
{
  pixels.begin(); // This initializes the NeoPixel library.
  pixels.setBrightness(50);
}

void LEDsOFF()
{
  for(int i=0;i<NUMPIXELS;i++)
  {
    pixels.setPixelColor(i, pixels.Color(0, 0, 0)); 
  }
  pixels.show();
}

void LEDsTest()
{
  for(int i=0;i<NUMPIXELS;i++)
  {
    pixels.setPixelColor(i, pixels.Color(255, 0, 0)); 
  }
  pixels.show(); // This sends the updated pixel color to the hardware.
  delay(1000);
  for(int i=0;i<NUMPIXELS;i++)
  {
    pixels.setPixelColor(i, pixels.Color(0, 255, 0)); 
  }
  pixels.show(); // This sends the updated pixel color to the hardware.
  delay(1000);
  for(int i=0;i<NUMPIXELS;i++)
  {
    pixels.setPixelColor(i, pixels.Color(0, 0, 255)); 
  }
  pixels.show(); // This sends the updated pixel color to the hardware.
  delay(1000);
  LEDsOFF();
}

void rotateFireWorks()
  /*  PURPOSE: 'Rotate' LED colors
        jrr, 2023-03-02: This function appears to "advance" the LED color
      when called. That is, the LEDs are lit, with a given color. This
      function increments each current R,G,B color value using some
      formula for that. So when called over time this has the effect
      of "rotating" the colors under the tubes. */
{
  if (tone1.isPlaying()) return; // jrr: If music is playing don't mess with the LEDs until it has stopped.
  if (!RGBLedsOn) // jrr: I assume RGBLedsOn is a flag indicating if the user has configured the backlight LEDs to be OFF or ON.
  {
    LEDsOFF();
    return;
  }
  if (LEDsLock) return;
  RedLight = RedLight + LEDsSpeed * fireforks[rotator * 3]; //jrr, 2023-03-02: Don't know what that fireforks[] is doing.
  GreenLight = GreenLight + LEDsSpeed * fireforks[rotator * 3 + 1];
  BlueLight = BlueLight + LEDsSpeed * fireforks[rotator * 3 + 2];

  for(int i=0;i<NUMPIXELS;i++)
  {
    pixels.setPixelColor(i, pixels.Color(RedLight, GreenLight, BlueLight)); 
  }

  pixels.show(); // This sends the updated pixel color to the hardware.
  
    /*   jrr, 2023-03-02: Have not tried to work out how this piece of code
      affects the color cycling. */
  cycle = cycle + 1;
  if (cycle == 255/LEDsSpeed)
  {
    rotator = rotator + 1;
    cycle = 0;
  }
  if (rotator > 5) rotator = 0;
}

void setLEDsFromEEPROM()
  /*  PURPOSE: light backlight LEDs if one color.
        This function lights the tube backlight RGB-LEDs when
      the user has configured them to be set to show one single
      color only (vs the default of rotating through color 
      changes).

    2023-03-02_a
      Modified to reduce the brightness of the LED that
      sits under the blinking dots column. See documentation
      item CD-03.
  */
{
  Serial.println("In setLEDsFromEEPROM()");

  float fDimFactor = (100-(float)COLdim)/100; // Dim column LED by this percentage 
  int R,G,B, Rc, Gc, Bc;
  
  R=EEPROM.read(LEDsRedValueEEPROMAddress);
  G=EEPROM.read(LEDsGreenValueEEPROMAddress);
  B=EEPROM.read(LEDsBlueValueEEPROMAddress);

  Rc = (int)(R * fDimFactor);
  Gc = (int)(G * fDimFactor);
  Bc = (int)(B * fDimFactor);

  for(int i=0;i<NUMPIXELS;i++)
  {
    if (i==2) { // pixel #2 is the dot-column LED pixel.
      pixels.setPixelColor(i, pixels.Color(Rc, Gc, Bc)); 
      Serial.print("Rc: "); Serial.println(Rc);
      Serial.print("Gc: "); Serial.println(Gc);
      Serial.print("Bc: "); Serial.println(Bc);
    }
    else { // digit tube LED pixels.
      pixels.setPixelColor(i, pixels.Color(R, G, B)); 
    }
  }
  pixels.show();
  Serial.println(F("LED Colors Read from EEPROM"));
  Serial.println(F("Digit Tube Values---"));
  Serial.print(F("   RED=")); Serial.println(R);
  Serial.print(F("   GREEN=")); Serial.println(G);
  Serial.print(F("   BLUE=")); Serial.println(B);
  Serial.println(F("Column Values---"));
  Serial.println(F("   Dimming Multiplier: ")); Serial.print(fDimFactor);
  Serial.print(F("      RED=")); Serial.println(Rc);
  Serial.print(F("      GREEN=")); Serial.println(Gc);
  Serial.print(F("      BLUE=")); Serial.println(Bc);
}

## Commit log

2023-02-12 removed several directories I won't be using or needing
    [NixieClockShield_NCS314.ino]
2023-02-12 CD-01 partial. Internal LED off, most of IR Remote code removed.
2023-02-12 Completed CD-01: Arduino internal LED off and removal of all IR Remote code.
2023-02-25 Added files for custom design and fabrication of a case.
    [FreeCAD_JeffsCase.FCStd]
2023-02-26 Updated FreeCAD model of case to generate solid forms.
    [FreeCAD_JeffsCase.FCStd]
2023-02-26 Added top plate to FreeCAD model of case.
    [FreeCAD_JeffsCase.FCStd]
2023-03-02 Made firmware update to dim dot-column LED.
2023-03-13 Added DST To-Do; Added updated user manual; Added board CAD file.
